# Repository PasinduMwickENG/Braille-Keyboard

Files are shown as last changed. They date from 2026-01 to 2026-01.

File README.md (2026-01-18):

# Braille Keyboard – Custom HID Device for Typing & Media Control

 <p float="left">
  
  
</p>

<p float="left">
  
  
</p>

A **custom Braille keyboard** built on ESP32 with USB HID support. This project allows users to type using Braille input, control media, and program custom macros directly via USB. It’s designed for accessibility, efficiency, and modular hardware customization.  

---

## 🛠 Features

- **Braille Input**  
  - Type letters, numbers, and punctuation using a 6-dot Braille system.  
  - Supports capitalization and numeric input modifiers.  

- **Secondary Numpad**  
  - Direct number input using a 6-button pad.  

- **Custom Keys**  
  - 3 programmable keys for macros.  
  - 3 media/control keys (volume, play/pause, next/previous).  
  - Multiple custom modes (Media, Modifiers, Programming).  

- **Special Keys**  
  - Dedicated Backspace, Enter, Space, Delete, and Caps Lock keys.  

- **Programming Mode**  
  - Easy macro programming stored in EEPROM.  

- **Robust USB HID Implementation**  
  - Works with both keyboards and consumer control (media) devices.  

---

## 🔧 Hardware Overview

### Pin Configuration

| Function | Pins |
|---|---|
| Braille Input | 6, 5, 4, 7, 15, 16 |
| Numpad Input | 8, 18, 17, 9, 10, 11 |
| Custom Keys | 12, 13, 14, 20, 45, 3 |
| Special Keys | SPACE: 38, ENTER: 42, BACKSPACE: 37, DELETE: 39, CAPSLOCK: 21 |
| Mode & Programming | MODE: 41, PROGRAM: 2, CUSTOM_MAIN: 46 |

---

### Hardware Components

- ESP32 microcontroller (any variant supporting USB HID)  
- Tactile push buttons for Braille input  
- Numpad buttons for secondary input  
- Custom/macro keys  
- Enclosure with key alignment and ergonomic layout  

---

## 🖥 PCB & Enclosure

### PCB Design

- Designed with KiCAD  
- 2-layer PCB supporting all input buttons and USB HID interface  
- Optimized for compact Braille keyboard layout

 <p float="left">
  
  
</p> 

### Enclosure

- 3D-printed  enclosure  
- Ergonomic key placement for Braille typing  
- Openings for USB and buttons  



---

## 💻 Software

### Libraries Used

- `USB.h` – USB core for ESP32 HID support  
- `USBHIDKeyboard.h` – Keyboard HID functions  
- `USBHIDConsumerControl.h` – Media/Consumer control HID  
- `EEPROM.h` – Store programmed macros  
- `esp_system.h` – System-level operations  

### Features

- Robust Braille mapping with letters and punctuation  
- Customizable macros via programming mode  
- Support for both media keys and modifier shortcuts  
- EEPROM storage to retain macros across power cycles  

### Usage

1. Connect the ESP32 to your PC via USB.  
2. Input letters using the Braille keys.  
3. Switch modes using the **Mode** button.  
4. Program macros using the **Program** button in Custom Mode 2.  

---

## 📝 Code Structure

- `setup()` – Initializes USB HID, EEPROM, and pins  
- `loop()` – Main logic for Braille input, numpad, custom keys, and special keys  
- `getBraille()` – Maps Braille patterns to letters/punctuation  
- `sendShortcut()` – Sends Ctrl-based keyboard shortcuts  
- `sendMedia()` – Sends media control codes  

---

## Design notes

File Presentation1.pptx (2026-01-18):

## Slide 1

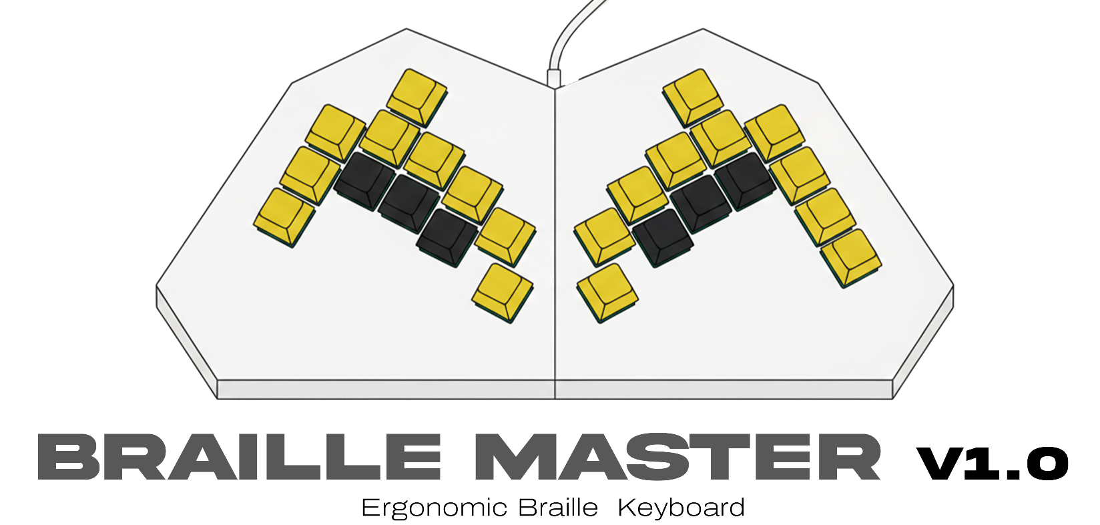
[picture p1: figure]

## Group 09

Ekanayake E.M.M.
Gamage N.N.J.
Nipun P.G.D.
Wickramanayake P.M.

E/20/097
E/20/111
E/20/269
E/20/436

## Content

1. Introduction
2. Problem
3. Solution
4. Design and Layout
5. Features
6. Use Cases
7. The Future
8. Conclusion

## Introduction

43 Million

Completely blind

According to WHO and IAPB:

2.2 Billion

People have a near or distance vision impairment

295 Million

Moderate to severe vision impairment

258 Million

Mild vision impairment

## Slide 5

The leading causes of visual impairment are age related (cataracts, muscle degeneration, etc.)
As the global population ages, the number of visually impaired people is projected to triple by 2050.
In the UK alone, 23% of visually impaired people say they never use the internet because of accessibility barriers.

## Problem

Standard interfaces create a digital barrier, effectively locking visually impaired individuals out of the modern world.
- Standard QWERT keyboards are hard to navigate and lack feedback.
- Touchscreens are even harder to navigate with the limited senses.
While some accessible products have their own unique challenges.

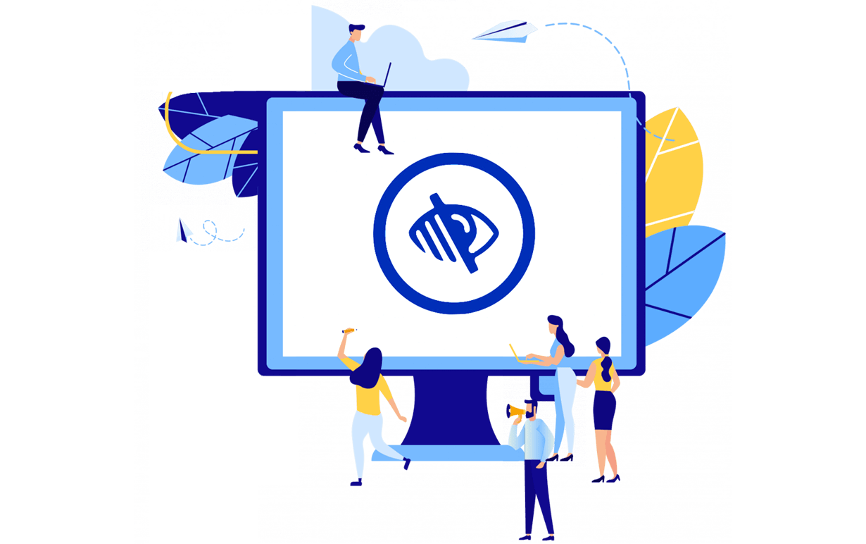
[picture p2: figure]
Update Your Web Accessibility for People with Visual Disabilities

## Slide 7

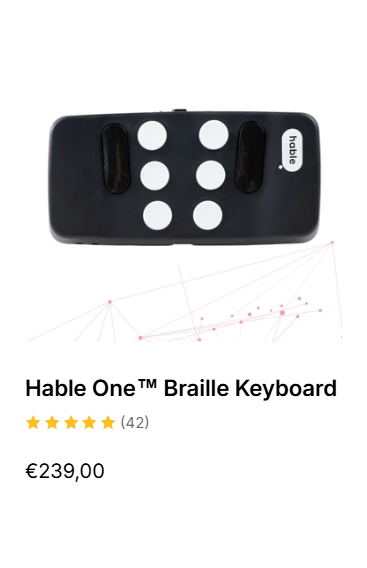
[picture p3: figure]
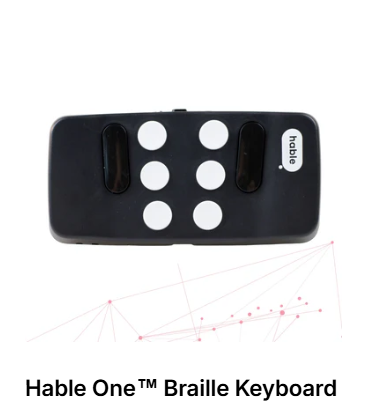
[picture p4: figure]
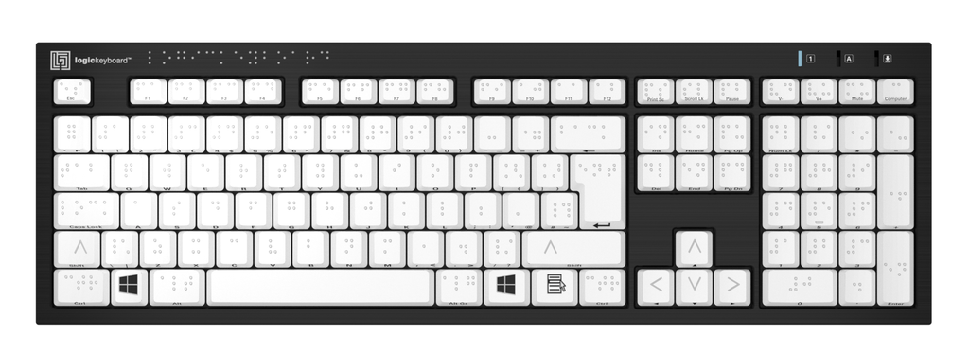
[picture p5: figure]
Logickeyboard braille keyboard for PC
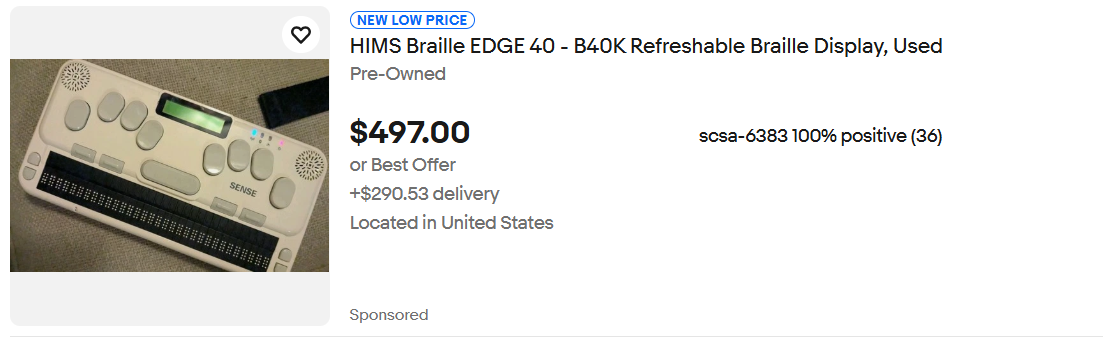
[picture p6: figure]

87 000 LKR

154 000 LKR

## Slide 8

Gathered from user reviews, Reddit and Quora conversations,

Existing keyboards for visually impaired individuals are,

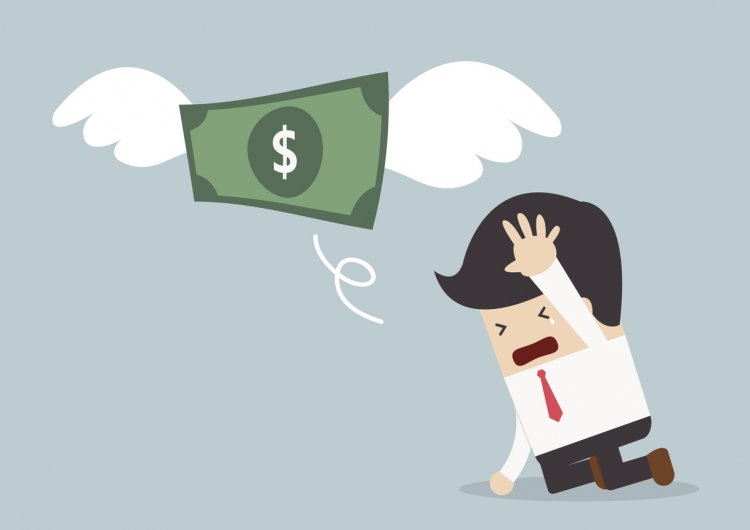
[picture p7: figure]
4 Most Expensive Mistakes Property Managers Make - @Assist Blog

- Expensive
- Too Heavy
- Too Slow
- Uncomfortable
- Unnecessarily complex

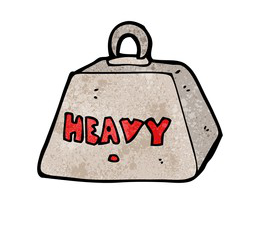
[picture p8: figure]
Cartoon Heavy Weight Symbol Stock Vector (Royalty Free) 121146274 | Shutterstock
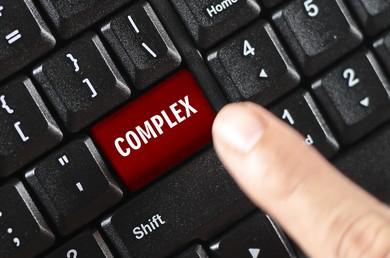
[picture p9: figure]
Complexity Word On Red Keyboard Button Stock Photo 515412514 | Shutterstock
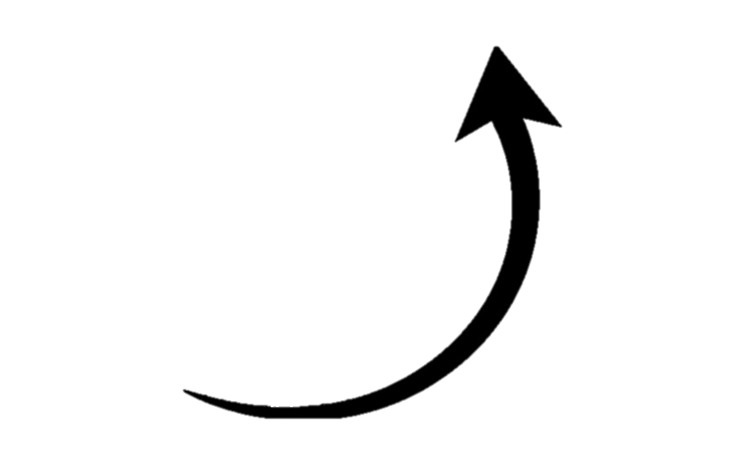
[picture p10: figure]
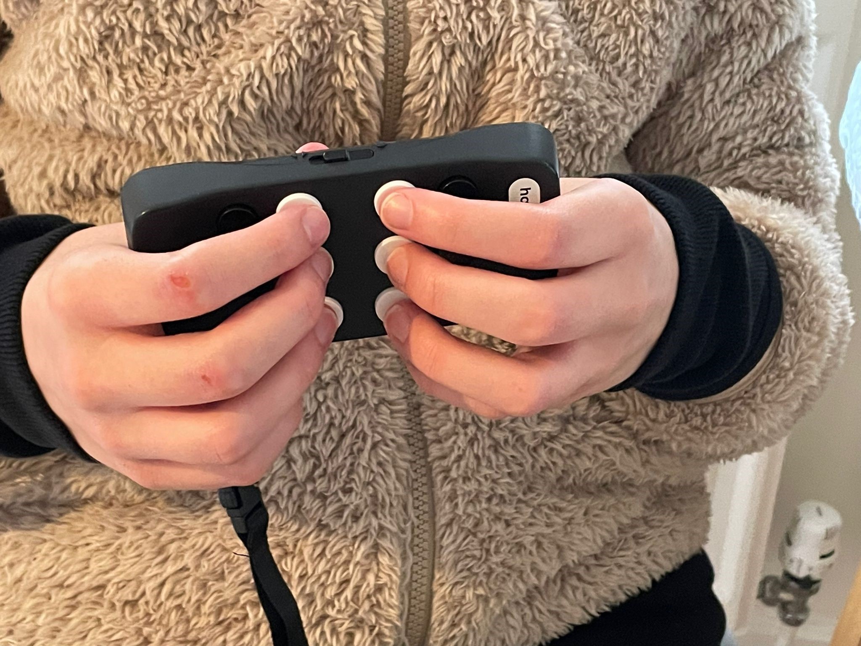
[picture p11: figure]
New Technology: The Hable One External Braille Keyboard - victastudents.org.uk
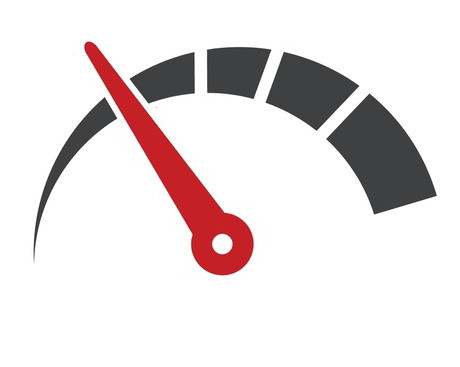
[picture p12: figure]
8,683 Drive Slow Stock Vectors and Vector Art | Shutterstock

## Solution

Braille Master

A simple, accessible, affordable, ergonomic keyboard with many features and customizability.

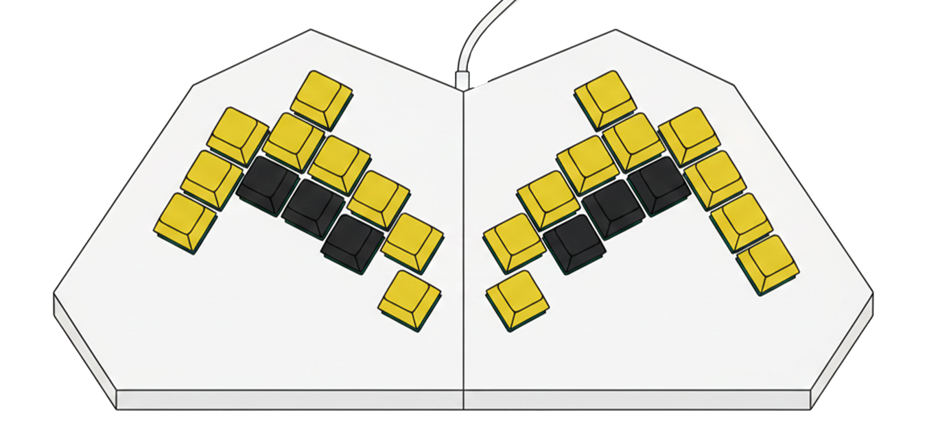
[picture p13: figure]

## Design and Layout

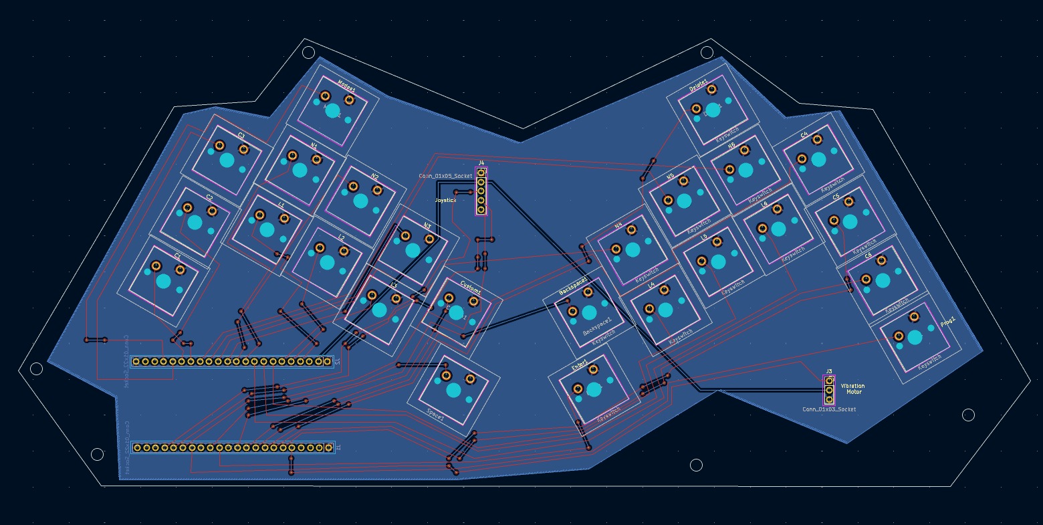
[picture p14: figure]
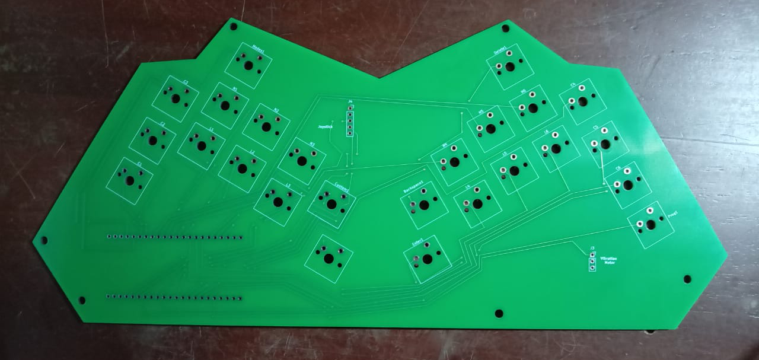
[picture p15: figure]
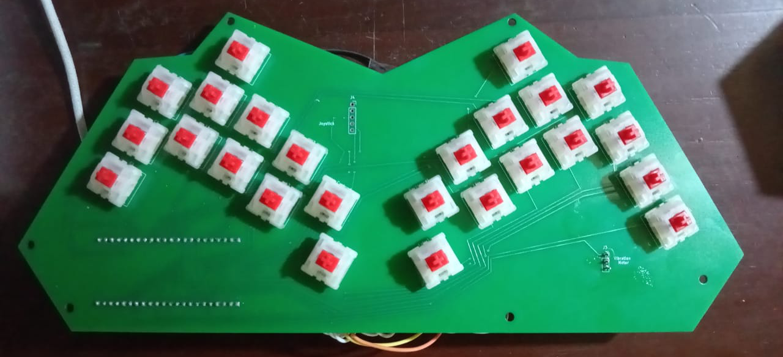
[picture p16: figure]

- KiCad
- Fusion 360

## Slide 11

Cost of a Unit

Item | Prices (LKR)
PCB | 3,614
Components | 2,500
Encloser | 3,825
Custom Key Caps | 1,100
Mechanical Keys | 3,100
Printing and Packaging | 1,800
Total | 15,939

*One fifth of a price of a existing braille keyboard!

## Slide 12

Mode Key

Number Keys

Delete

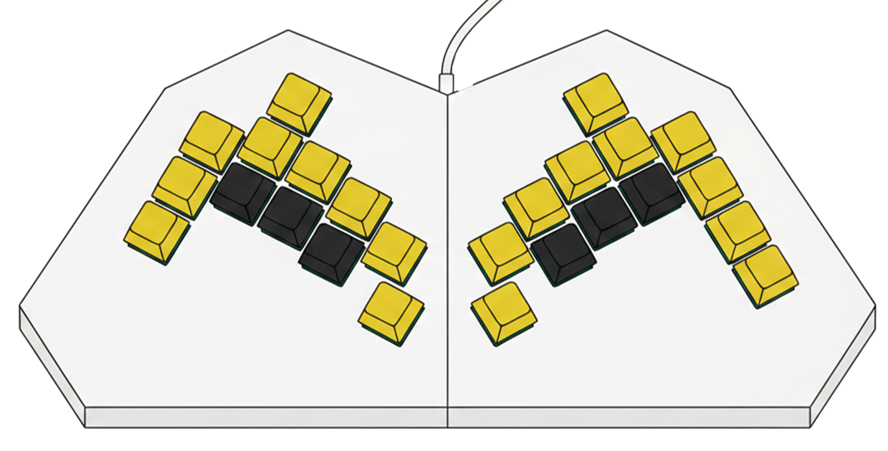
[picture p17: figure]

Custom Keys

Feature Keys

Program Key

Enter

Braille Keys

Backspace

Caps Lock

Space

## Features

- USB-C Compatible – Plug and play, no additional drivers are required.
- 25 Mechanical keys for smooth and satisfying feel.
- Ergonomic design for comfortability.
- Custom printed concave and flat keycaps for easy identification.
- Windows and Linux Support.
- Optimized for NVDA and JAWS screen readers
- Splash-resistant chassis for durability

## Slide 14

Modes:
- Mode 1: Media Control (Default)
Top Key: Next Track
Middle Key: Play/Pause
Bottom Key: Previous Track
- Mode 2: System Modifiers (One Press)
Top Key: Control (Ctrl)
Middle Key: Alt
Bottom Key: Windows Key
- Mode 3: Clipboard (Two Presses)
Top Key: Paste
Middle Key: Cut
Bottom Key: Copy

- Customizable Keys
can use to add characters to these keys using the program key.

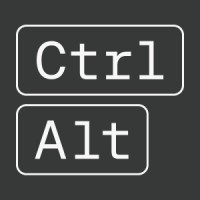
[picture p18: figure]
Ctrl Alt | LinkedIn
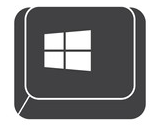
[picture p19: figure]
57+ Thousand Windows Key Royalty-Free Images, Stock Photos & Pictures | Shutterstock
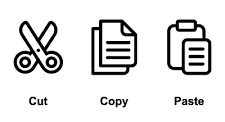
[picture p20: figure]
The Fascinating History of the Cut, Copy, and Paste Shortcuts - Hexafusion IT Solutions Blog | Vancouver, BC | Hexafusion IT Solutions
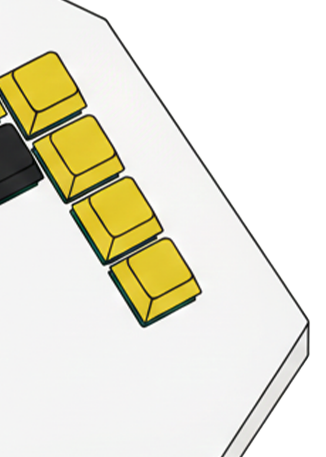
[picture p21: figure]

Custom Keys

Program Key

## Use Cases

- For students to take notes in class quietly.
- For programmers to write code easily and save custom characters.
- For musicians to use media controls while listening to audio tracks.

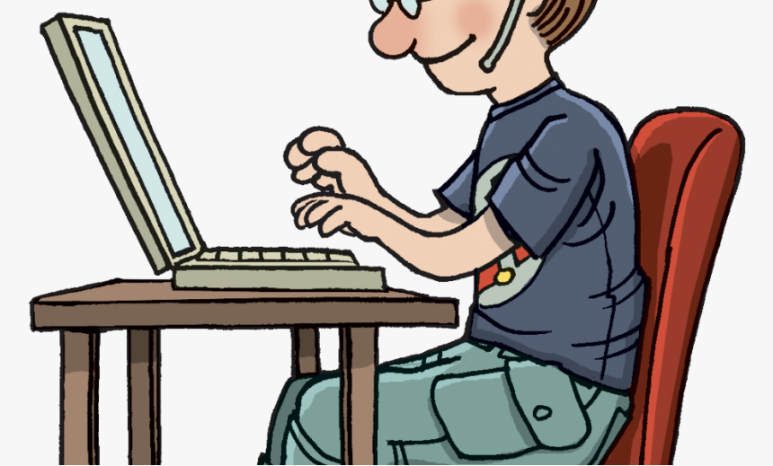
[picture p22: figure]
Transparent Student Typing Clipart - Typing In The Computer Clipart, HD Png Download - kindpng
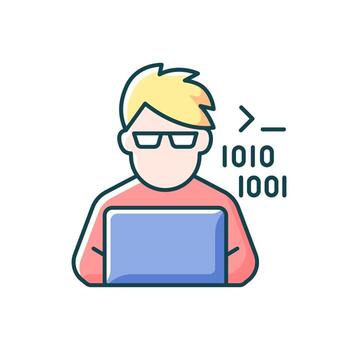
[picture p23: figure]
Computer Programmer Vector Art, Icons, and Graphics for Free Download
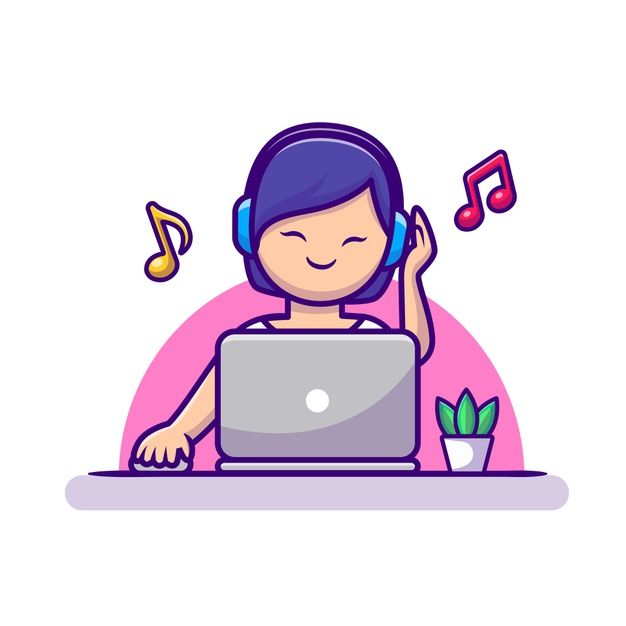
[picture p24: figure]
Girl listening music with headphone and laptop cartoon vector icon illustration. people technology icon concept isolated premium vector. flat cartoon style | Premium Vector

## The Future

- Joystick for easy navigation. (make the keyboard all in one product).
- Introduce Bluetooth accessibility for tabs and smart phone use.
- Integrate refreshable braille display.
- Introduce a software for specific customizations.

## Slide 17

Conclusion

We have taken the durability of mechanical switches, the speed of Perkins-style input, and the intelligence of modern macros—and combined them into one affordable, easy to use and accessible device.

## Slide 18

THANK YOU

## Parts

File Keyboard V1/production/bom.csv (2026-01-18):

Designator | Footprint | Quantity | Value | LCSC Part #
BACKSPACE1, C1, C2, C3, C4, C5, C6, CUSTOM1, DELETE1, ENTER1, L1, L2, L3, L4, L5, L6, MODES1, N1, N2, N3, N4, N5, N6, PROG1, SPACE1 | MX_PCB_1.00u | 25 | Keyswitch
J1, J2 | PinSocket_1x22_P2.54mm_Vertical | 2 | Conn_01x22_Socket
J3 | PinSocket_1x03_P2.54mm_Vertical | 1 | Conn_01x03_Socket
J4 | PinSocket_1x05_P2.54mm_Vertical | 1 | Conn_01x05_Socket

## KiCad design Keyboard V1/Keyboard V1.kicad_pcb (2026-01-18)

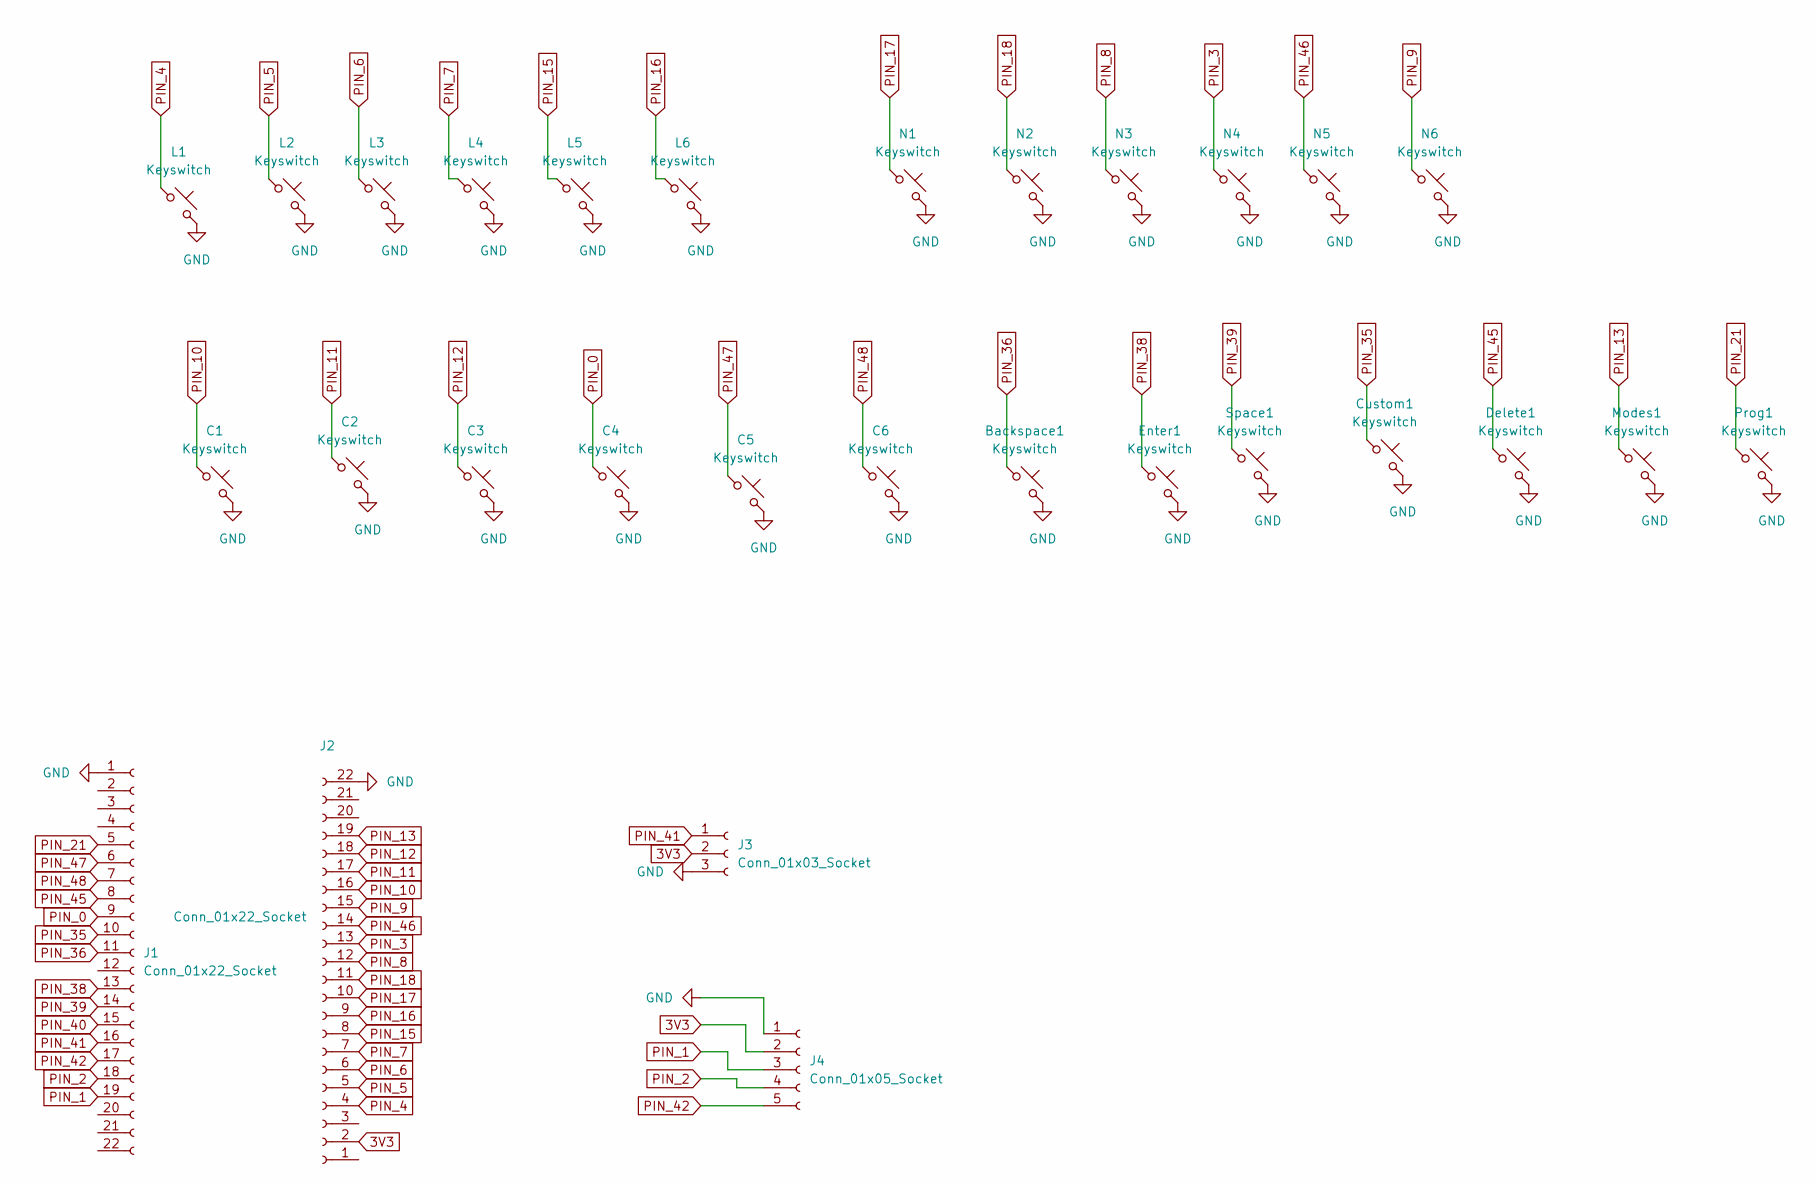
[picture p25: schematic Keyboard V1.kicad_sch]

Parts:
Backspace1: Keyswitch; MX_PCB_1.00u
C1, C2, C3, C4, C5, C6: Keyswitch; MX_PCB_1.00u
Custom1: Keyswitch; MX_PCB_1.00u
Delete1: Keyswitch; MX_PCB_1.00u
Enter1: Keyswitch; MX_PCB_1.00u
J1, J2: Conn_01x22_Socket; PinSocket_1x22_P2.54mm_Vertical
J3: Conn_01x03_Socket; PinSocket_1x03_P2.54mm_Vertical
J4: Conn_01x05_Socket; PinSocket_1x05_P2.54mm_Vertical
L1, L2, L3, L4, L5, L6: Keyswitch; MX_PCB_1.00u
Modes1: Keyswitch; MX_PCB_1.00u
N1, N2, N3, N4, N5, N6: Keyswitch; MX_PCB_1.00u
Prog1: Keyswitch; MX_PCB_1.00u
Space1: Keyswitch; MX_PCB_1.00u

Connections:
3V3: J2.2, J3.2, J4.2
GND: Backspace1.2, C1.2, C2.2, C3.2, C4.2, C5.2, C6.2, Custom1.2, Delete1.2, Enter1.2, J1.1, J2.22, J3.3, J4.1, L1.2, L2.2, L3.2, L4.2, L5.2, L6.2, Modes1.2, N1.2, N2.2, N3.2, N4.2, N5.2, N6.2, Prog1.2, Space1.2
PIN_0: C4.1, J1.9
PIN_1: J1.19, J4.3
PIN_2: J1.18, J4.4
PIN_3: J2.13, N4.1
PIN_4: J2.4, L1.1
PIN_5: J2.5, L2.1
PIN_6: J2.6, L3.1
PIN_7: J2.7, L4.1
PIN_8: J2.12, N3.1
PIN_9: J2.15, N6.1
PIN_10: C1.1, J2.16
PIN_11: C2.1, J2.17
PIN_12: C3.1, J2.18
PIN_13: J2.19, Modes1.1
PIN_15: J2.8, L5.1
PIN_16: J2.9, L6.1
PIN_17: J2.10, N1.1
PIN_18: J2.11, N2.1
PIN_21: J1.5, Prog1.1
PIN_35: Custom1.1, J1.10
PIN_36: Backspace1.1, J1.11
PIN_38: Enter1.1, J1.13
PIN_39: J1.14, Space1.1
PIN_40: J1.15
PIN_41: J1.16, J3.1
PIN_42: J1.17, J4.5
PIN_45: Delete1.1, J1.8
PIN_46: J2.14, N5.1
PIN_47: C5.1, J1.6
PIN_48: C6.1, J1.7

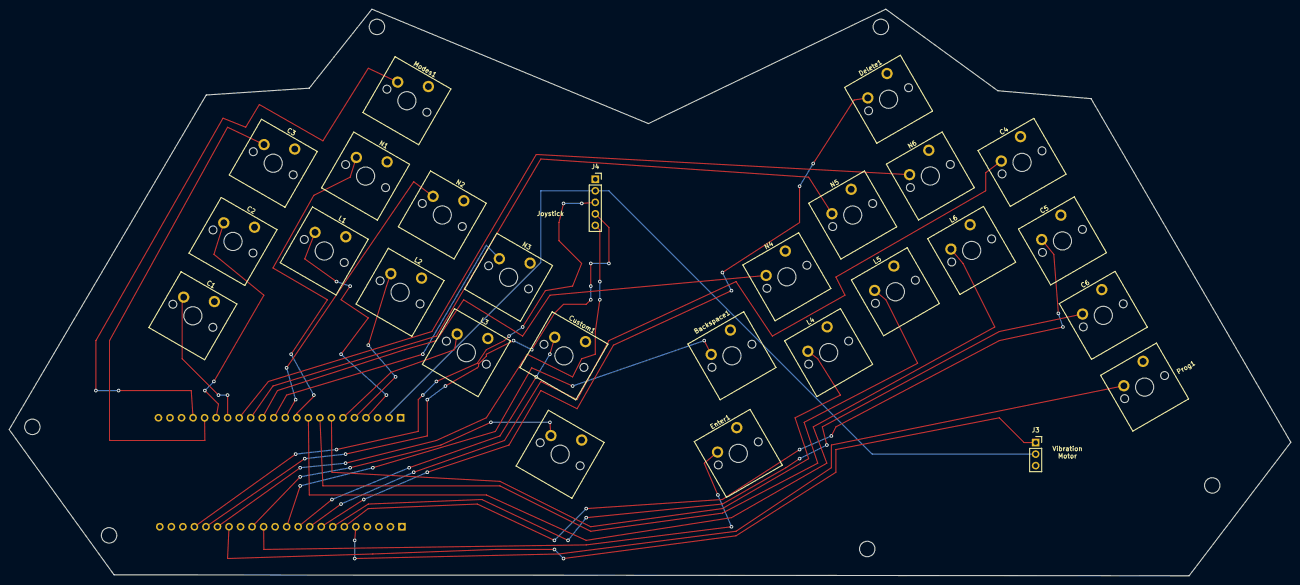
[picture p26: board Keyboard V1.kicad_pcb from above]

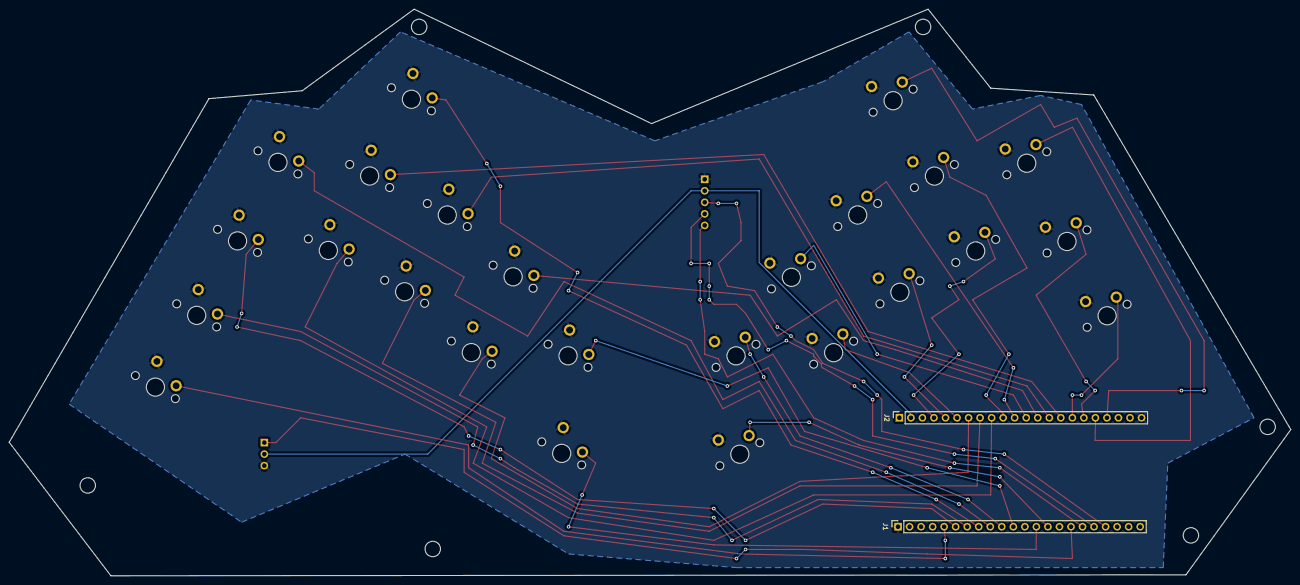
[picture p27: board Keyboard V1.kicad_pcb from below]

Board: 4 copper layers, 282.3 x 124.8 mm, 29 parts (2 on the bottom side), 31 nets.

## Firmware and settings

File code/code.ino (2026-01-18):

#include "USB.h"
#include "USBHIDKeyboard.h"
#include "USBHIDConsumerControl.h"
#include <EEPROM.h>
#include "esp_system.h"

USBHIDKeyboard Keyboard;
USBHIDConsumerControl Consumer;

// =====================
// Pin Definitions
// =====================
const int braillePins[6] = {6, 5, 4, 7, 15, 16};
const int numPadPins[6]  = {8, 18, 17, 9, 10, 11};
const int customKeys[6]  = {12, 13, 14, 20, 45, 3}; 

#define CUSTOM_MAIN_PIN 46
#define BACKSPACE_PIN   37
#define ENTER_PIN       42  
#define SPACE_PIN       38  
#define DELETE_PIN      39
#define PROGRAM_PIN     2
#define MODE_PIN        41
#define CAPSLOCK_PIN    21

// =====================
// States & Variables
// =====================
uint8_t braillePattern = 0;
bool brailleActive = false;
uint8_t numPattern = 0;
bool numActive = false;

// Braille Modifiers
bool nextIsCap = false;
bool nextIsNum = false;

uint8_t customMode = 0; 
bool processed[6] = {false}; 
bool specProcessed[5] = {false}; 

char programmedChars[3] = {' ', ' ', ' '}; 
bool isProgramming = false;
int keyToProgram = -1;

// =====================
// Robust HID Helpers
// =====================
void sendShortcut(char key) {
  Keyboard.press(KEY_LEFT_CTRL);
  delay(30); 
  Keyboard.press(key);
  delay(50);
  Keyboard.release(key); 
  delay(30);
  Keyboard.release(KEY_LEFT_CTRL);
}

void sendMedia(uint16_t code) {
  Consumer.press(code);
  delay(150); 
  Consumer.release();
}

struct BrailleMap {
  uint8_t pattern;
  char letter;
};

// Expanded Braille Table (Letters + Punctuation)
BrailleMap brailleTable[] = {
  {0b000001,'a'}, {0b000011,'b'}, {0b001001,'c'}, {0b011001,'d'},
  {0b010001,'e'}, {0b001011,'f'}, {0b011011,'g'}, {0b010011,'h'},
  {0b001010,'i'}, {0b011010,'j'}, {0b000101,'k'}, {0b000111,'l'},
  {0b001101,'m'}, {0b011101,'n'}, {0b010101,'o'}, {0b001111,'p'},
  {0b011111,'q'}, {0b010111,'r'}, {0b001110,'s'}, {0b011110,'t'},
  {0b100101,'u'}, {0b100111,'v'}, {0b111010,'w'}, {0b101101,'x'},
  {0b111101,'y'}, {0b110101,'z'},
  // Punctuation
  {0b000010,','}, {0b000110,';'}, {0b010010,':'}, {0b010110,'.'},
  {0b010100,'?'}, {0b010011,'!'}, {0b001100,'\"'},{0b000100,'\''},
  {0b100001,'-'}, {0b001100,'/'}, {0b011100,'@'}
};

char getBraille(uint8_t p) {
  for (auto &b : brailleTable) if (b.pattern == p) return b.letter;
  return 0;
}

char letterToNumber(char c) {
  if (c >= 'a' && c <= 'i') return (char)(c - 'a' + '1');
  if (c == 'j') return '0';
  return c;
}

// =====================
// SETUP
// =====================
void setup() {
  USB.begin();
  Keyboard.begin();
  Consumer.begin();
  EEPROM.begin(32);

  for(int i=0; i<3; i++) {
    programmedChars[i] = EEPROM.read(i);
    if (programmedChars[i] == 255 || programmedChars[i] == 0) programmedChars[i] = ' '; 
  }

  for (int i = 0; i < 6; i++) {
    pinMode(braillePins[i], INPUT_PULLUP);
    pinMode(numPadPins[i], INPUT_PULLUP);
    pinMode(customKeys[i], INPUT_PULLUP);
  }

  pinMode(BACKSPACE_PIN, INPUT_PULLUP);
  pinMode(ENTER_PIN, INPUT_PULLUP);
  pinMode(SPACE_PIN, INPUT_PULLUP);
  pinMode(DELETE_PIN, INPUT_PULLUP);
  pinMode(PROGRAM_PIN, INPUT_PULLUP);
  pinMode(MODE_PIN, INPUT_PULLUP);
  pinMode(CAPSLOCK_PIN, INPUT_PULLUP);
}

// =====================
// LOOP
// =====================
void loop() {
  static bool modeWas = HIGH, progWas = HIGH;
  bool modeNow = digitalRead(MODE_PIN);
  bool progNow = digitalRead(PROGRAM_PIN);

  if (modeNow == LOW && modeWas == HIGH) { customMode = (customMode + 1) % 3; delay(200); }
  if (progNow == LOW && progWas == HIGH && customMode == 2) { isProgramming = true; keyToProgram = -1; delay(200); }
  
  modeWas = modeNow;
  progWas = progNow;

  // --- MAIN BRAILLE LOGIC ---
  uint8_t bp = 0;
  for (int i = 0; i < 6; i++) if (digitalRead(braillePins[i]) == LOW) bp |= (1 << i);
  
  if (bp) { 
    braillePattern |= bp; 
    brailleActive = true; 
  } 
  else if (brailleActive) {
    // Special Indicators
    if (braillePattern == 0b100000) {      // Dot 6: Capital Next
      nextIsCap = true;
    } 
    else if (braillePattern == 0b111100) { // Dots 3,4,5,6: Number Next
      nextIsNum = true;
    }
    else {
      char c = getBraille(braillePattern);
      if (c) {
        if (nextIsNum) { c = letterToNumber(c); nextIsNum = false; }
        if (nextIsCap) { if(c >= 'a' && c <= 'z') c -= 32; nextIsCap = false; }

        if (isProgramming && keyToProgram != -1) {
          programmedChars[keyToProgram] = c;
          EEPROM.write(keyToProgram, (uint8_t)c);
          EEPROM.commit();
          isProgramming = false; keyToProgram = -1;
        } else { 
          Keyboard.write(c); 
        }
      }
    }
    braillePattern = 0; brailleActive = false;
  }

  // --- SECONDARY NUMPAD LOGIC (Direct) ---
  uint8_t np = 0;
  for (int i = 0; i < 6; i++) if (digitalRead(numPadPins[i]) == LOW) np |= (1 << i);
  if (np) { numPattern |= np; numActive = true; } 
  else if (numActive) {
    char l = getBraille(numPattern);
    if (l) Keyboard.write(letterToNumber(l));
    numPattern = 0; numActive = false;
  }

  // --- CUSTOM KEYS ---
  for (int i = 0; i < 6; i++) {
    bool isPressed = (digitalRead(customKeys[i]) == LOW);
    if (isPressed && !processed[i]) {
      processed[i] = true; 
      if (isProgramming && i >= 3) { keyToProgram = i - 3; } 
      else if (customMode == 0) { // MEDIA
        if (i == 0) sendMedia(0xB6); if (i == 1) sendMedia(0xCD);
        if (i == 2) sendMedia(0xB5); if (i == 3) sendMedia(0xE2);
        if (i == 4) sendMedia(0xE9); if (i == 5) sendMedia(0xEA);
      } 
      else if (customMode == 1) { // MODIFIERS (Sticky)
        if (i == 0) Keyboard.press(KEY_LEFT_GUI);
        if (i == 1) Keyboard.press(KEY_LEFT_ALT);
        if (i == 2) Keyboard.press(KEY_LEFT_CTRL);
        if (i == 3) sendShortcut('z'); 
        if (i == 4) sendShortcut('y'); 
        if (i == 5) sendShortcut('s'); 
      } 
      else if (customMode == 2) { // PROG/MACRO
        if (i == 0) sendShortcut('c'); 
        if (i == 1) sendShortcut('x'); 
        if (i == 2) sendShortcut('v'); 
        if (i >= 3 && programmedChars[i-3] != ' ') Keyboard.write(programmedChars[i-3]);
      }
    } 
    if (!isPressed) {
      if (processed[i] && customMode == 1 && i < 3) { Keyboard.releaseAll(); }
      processed[i] = false; 
    }
  }

  // --- SPECIAL KEYS ---
  int pins[] = {SPACE_PIN, ENTER_PIN, BACKSPACE_PIN, DELETE_PIN, CAPSLOCK_PIN};
  uint8_t keys[] = {' ', KEY_RETURN, KEY_BACKSPACE, KEY_DELETE, KEY_CAPS_LOCK};
  for(int i=0; i<5; i++) {
    bool p = (digitalRead(pins[i]) == LOW);
    if (p && !specProcessed[i]) { Keyboard.write(keys[i]); specProcessed[i] = true; }
    if (!p) specProcessed[i] = false;
  }

  delay(10); 
}
